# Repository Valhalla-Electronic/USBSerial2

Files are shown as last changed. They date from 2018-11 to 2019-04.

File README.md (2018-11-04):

# Freetronics USB to Serial converter

Can also be used as an atmega16u2 breakout/development board.

For full details see [http://freetronics.com/usbserial](http://freetronics.com/usbserial)

[View Schematic as PDF](https://github.com/freetronics/USBSerial/raw/master/USBSerial.pdf)

Design (C) 2013 Freetronics Pty Ltd
Published under the [TAPR Open Hardware License](http://tapr.org/ohl)

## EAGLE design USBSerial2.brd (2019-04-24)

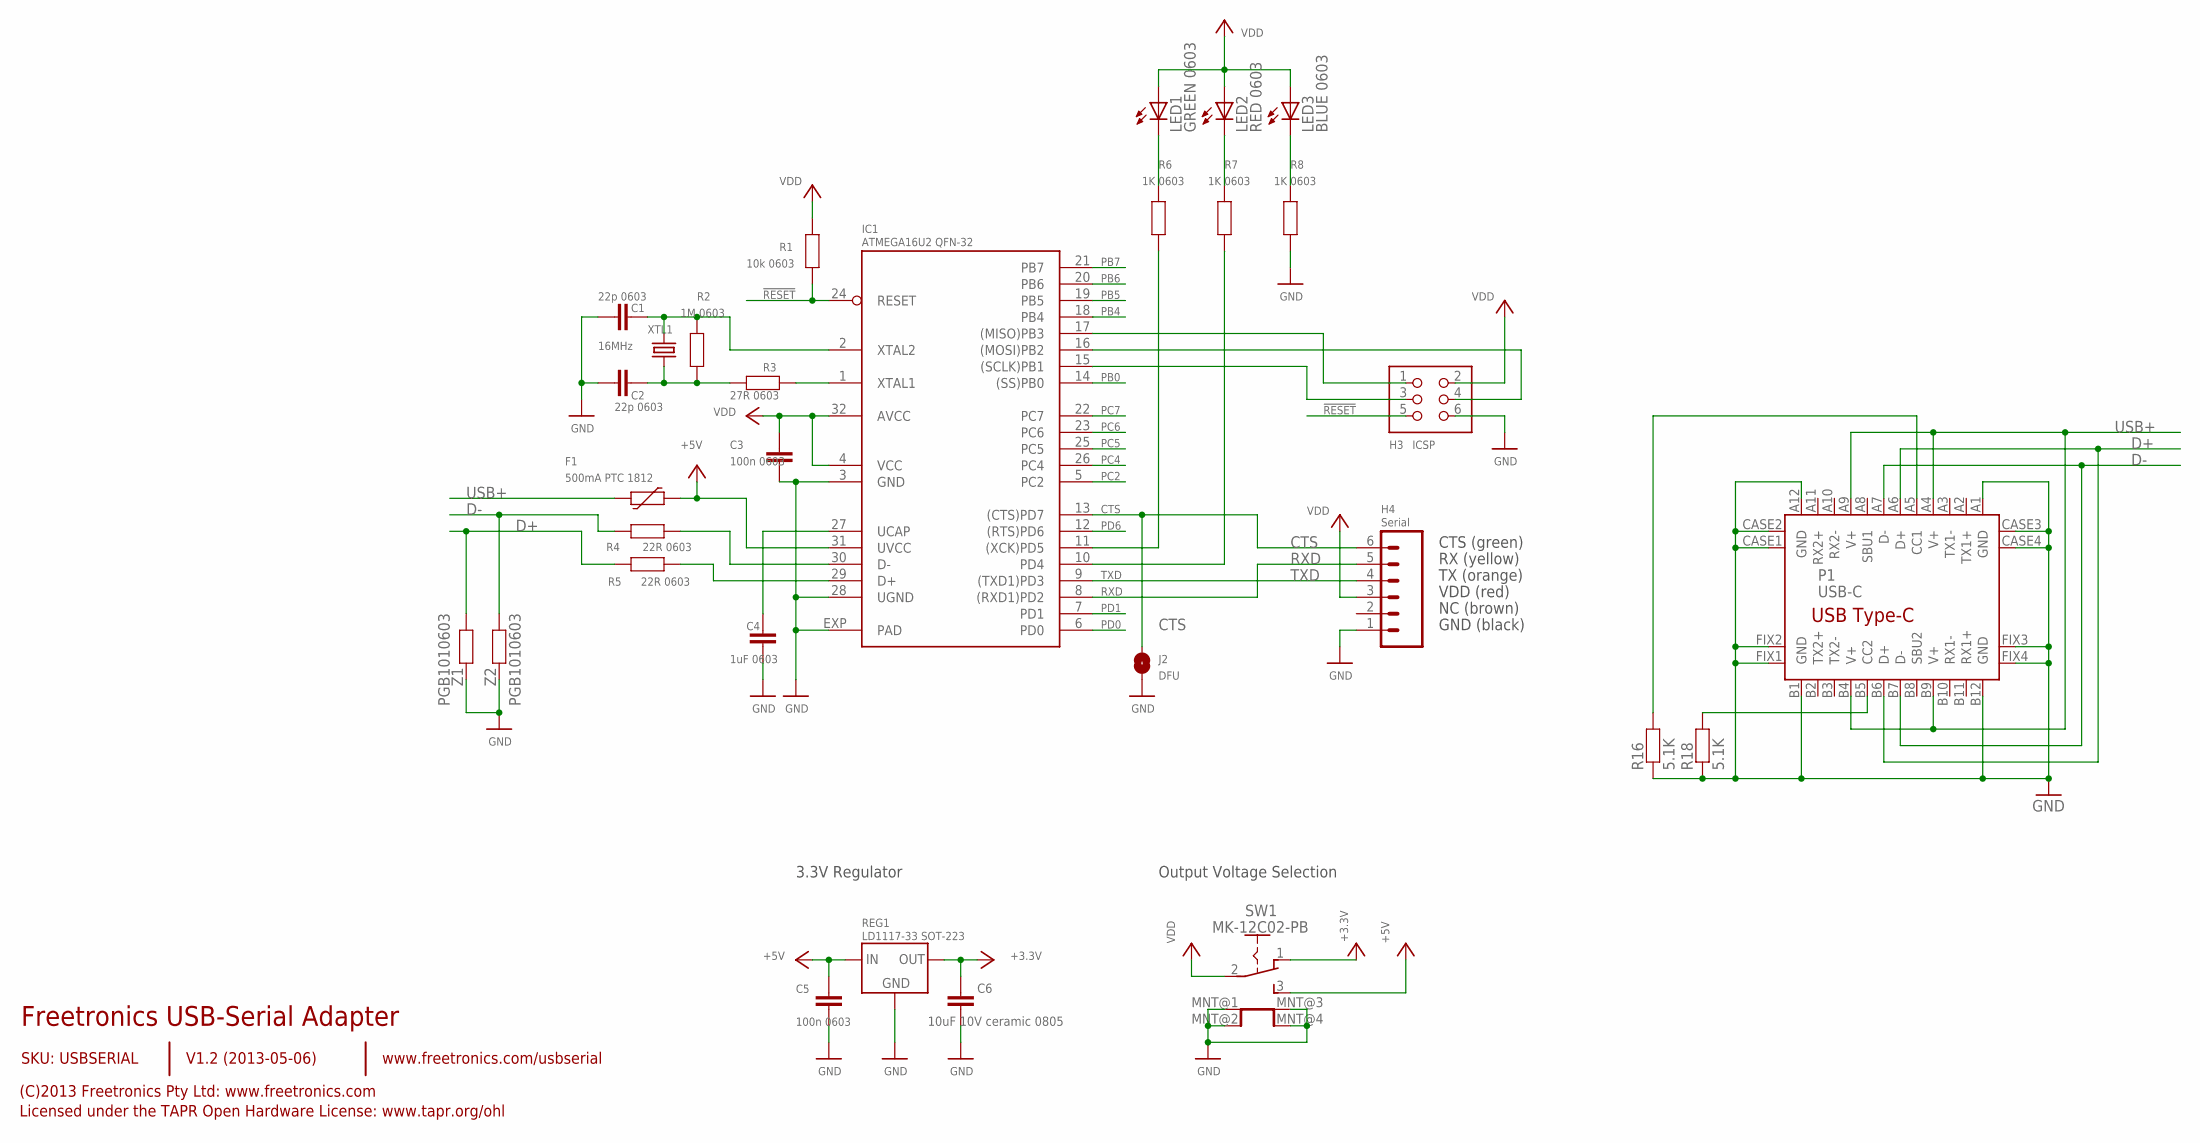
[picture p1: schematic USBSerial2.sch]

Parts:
C1, C2: 22p 0603; 0603
C3, C5: 100n 0603; 0603
C4: 1uF 0603; 0603
C6: 10uF 10V ceramic 0805; C0805
F1: 500mA PTC 1812; 1812
H3: ICSP; HEADER_2X3
H4: Serial; 1X06
IC1: ATMEGA16U2 QFN-32; ATMEL_QFN32
J2: DFU; SJ
LED1: GREEN 0603; LED-0603
LED2: RED 0603; LED-0603
LED3: BLUE 0603; LED-0603
P1: USB-C; USB-C-U52A
R1: 10k 0603; 0603
R2: 1M 0603; 0603
R3: 27R 0603; 0603
R4, R5: 22R 0603; 0603
R6, R7, R8: 1K 0603; 0603
R16, R18: 5.1K; 0603
REG1: LD1117-33 SOT-223; SOT-223
SW1: MK-12C02-PB; MK-12C02
XTL1: 16MHz; HC49U-V
Z1, Z2: PGB1010603; 0603

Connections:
!RESET: H3.5, IC1.24 (RESET), R1.1
+3V3: C6.1, REG1.2 (OUT), REG1.4 (OUT), SW1.1 (A)
+5V: C5.1, F1.2, IC1.31 (UVCC), REG1.3 (IN), SW1.3 (B)
CTS: H4.6, IC1.13 ((CTS)PD7), J2.2
D+: P1.A6 (D+), P1.B6 (D+), R5.2, Z1.1
D-: P1.A7 (D-), P1.B7 (D-), R4.2, Z2.1
GND: C1.1, C2.1, C3.2, C4.2, C5.2, C6.2, H3.6, H4.1, IC1.3 (GND), IC1.28 (UGND), IC1.EXP (PAD), J2.1, P1.A1 (GND), P1.A12 (GND), P1.B1 (GND), P1.B12 (GND), P1.CASE1 (GND), P1.CASE2 (GND), P1.CASE3 (GND), P1.CASE4 (GND), P1.FIX1 (GND), P1.FIX2 (GND), P1.FIX3 (GND), P1.FIX4 (GND), R8.1, R16.1, R18.1, REG1.1 (GND), SW1.MNT@1 (MNT), SW1.MNT@2 (MNT), SW1.MNT@3 (MNT), SW1.MNT@4 (MNT), Z1.2, Z2.2
MISO: H3.1, IC1.17 ((MISO)PB3)
MOSI: H3.4, IC1.16 ((MOSI)PB2)
unnamed: IC1.1 (XTAL1), R3.1
unnamed: LED1.C, R6.2
unnamed: P1.A5 (CC1), R16.2
unnamed: P1.B5 (CC2), R18.2
unnamed: LED2.C, R7.2
unnamed: LED3.C, R8.2
unnamed: C1.2, IC1.2 (XTAL2), R2.2, XTL1.2
unnamed: C2.2, R2.1, R3.2, XTL1.1
unnamed: C4.1, IC1.27 (UCAP)
PB0: IC1.14 ((SS)PB0)
PB4: IC1.18 (PB4)
PB5: IC1.19 (PB5)
PB6: IC1.20 (PB6)
PB7: IC1.21 (PB7)
PC2: IC1.5 (PC2)
PC4: IC1.26 (PC4)
PC5: IC1.25 (PC5)
PC6: IC1.23 (PC6)
PC7: IC1.22 (PC7)
PD0: IC1.6 (PD0)
PD1: IC1.7 (PD1)
PD6: IC1.12 ((RTS)PD6)
RD+: IC1.29 (D+), R5.1
RD-: IC1.30 (D-), R4.1
RXD: H4.5, IC1.8 ((RXD1)PD2)
RXLED: IC1.10 (PD4), R7.1
SCK: H3.3, IC1.15 ((SCLK)PB1)
TXD: H4.4, IC1.9 ((TXD1)PD3)
TXLED: IC1.11 ((XCK)PD5), R6.1
USB+: F1.1, P1.A4 (V+), P1.A9 (V+), P1.B4 (V+), P1.B9 (V+)
VDD: C3.1, H3.2, H4.3, IC1.4 (VCC), IC1.32 (AVCC), LED1.A, LED2.A, LED3.A, R1.2, SW1.2 (COM)

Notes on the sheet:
Freetronics USB-Serial Adapter
V1.2 (2013-05-06)
SKU: USBSERIAL
(C)2013 Freetronics Pty Ltd: www.freetronics.com
Licensed under the TAPR Open Hardware License: www.tapr.org/ohl
www.freetronics.com/usbserial
CTS (green)
RX (yellow)
TX (orange)
VDD (red)
NC (brown)
GND (black)
Output Voltage Selection
3.3V Regulator

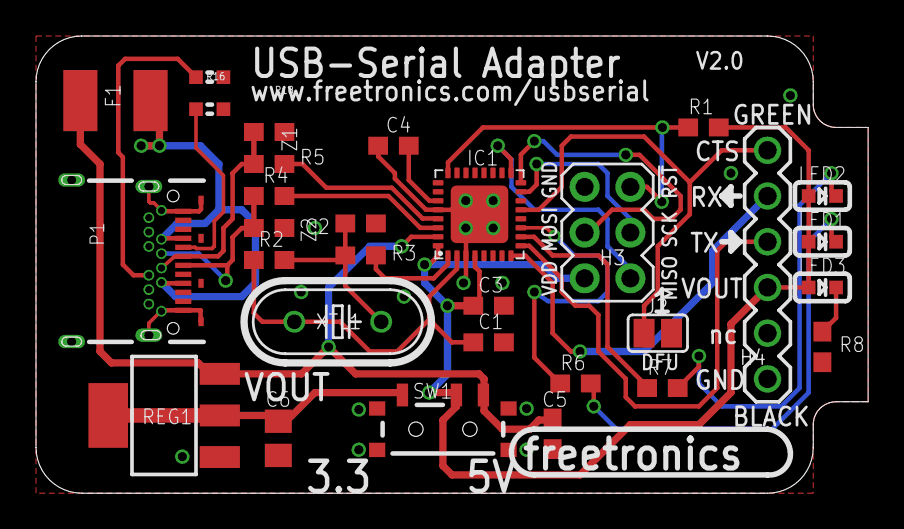
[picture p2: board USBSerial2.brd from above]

Board: 2 copper layers, 46.2 x 25.4 mm, 30 parts (0 on the bottom side), 27 nets.

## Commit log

2013-04-17 Changed CTS / RTS assignment
    [USBSerial.brd, USBSerial.sch]
2013-04-17 v1.1 release: Separate LEDs near TX/RX/VCC pins; PCB tab over connector; label improvements
    [USBSerial.brd, USBSerial.sch]
2014-01-17 Add README, schematic PDF
2018-11-04 Minor cleanups for v1.2 release
    [USBSerial.brd, USBSerial.sch]
2019-04-24 Replaced USB connector with USB-C
    [USBSerial.brd, USBSerial.sch]
2019-04-24 Renamed project files
    [USBSerial2.brd, USBSerial2.sch]

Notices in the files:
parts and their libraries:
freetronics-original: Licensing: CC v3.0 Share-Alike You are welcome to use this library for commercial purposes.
